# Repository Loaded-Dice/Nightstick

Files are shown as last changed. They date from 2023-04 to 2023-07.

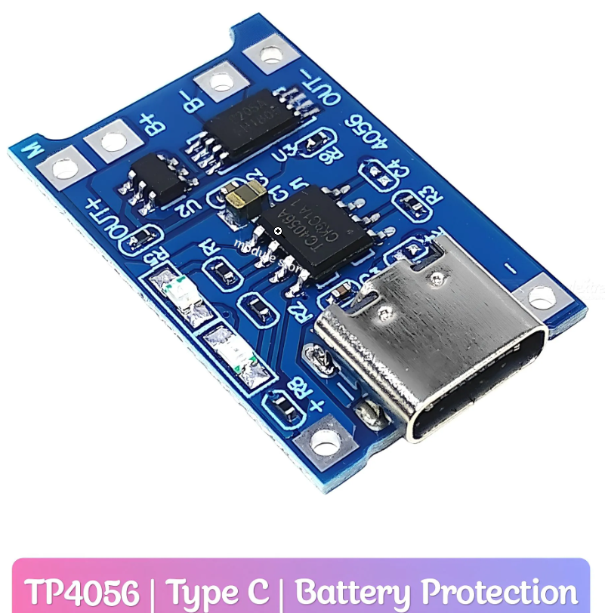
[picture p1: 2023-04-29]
Nightstick - DIY tutorial and Infos/LiPo Battery Charger Image.png

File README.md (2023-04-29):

# Nightstick
 
 Artistic LED toy - POV display style animated LEDs Arduino based code and DIY tutorial
 
 The main idea is to track the movement of the stick with an IMU (inertial measurement unit) 
 and display static images while the Nightstick is rotating
 
 This is not my first project, but the first one I publish on GitHub.
 
 Any tips, contributions or improvements are welcome.
 
 I'm still figuring things out :) 
 
 Readme Nightstick Main image

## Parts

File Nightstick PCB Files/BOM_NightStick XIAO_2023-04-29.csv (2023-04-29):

ID | Name | Designator | Footprint | Quantity | Manufacturer Part | Manufacturer | Supplier | Supplier Part | Price | link
1 | 100nF | C2,C5 | C0603 | 2
2 | 0.1u | C3 | C0603 | 1
3 | 1u | C4 | CAP-D5.0×F2.0 | 1
4 | TF-015 | CARD2 | TF-SMD_TF-015 | 1 | TF-015 | SOFNG | LCSC | C113206 | 0.031
5 | BSS138 | Q3 | BSS138 | 1 | BSS138 | ON Semiconductor | RS-Online | 671-0324 |  | https://www.onsemi.com/products/discretes-drivers/mosfets/bss138
6 | 10k | R1,R2,R3,R4,R5,R6 | R0603 | 6
7 | XIAO_NRF52840_SMD+Bat.TH | U1 | XIAO-NRF52840-SMD+BAT.TH | 1
8 | HW-373 6 Pin Batt Charger & BLM | U2 | HW-373 6 PIN BATT CHARGE & BLM | 1 | HW-373 | Shenzhen Hairuixing Technology Co., Ltd. |  | HW-373 |  | https://arduino.en.alibaba.com/product/62560363653-813084145/HW_373_1A_lithium_battery_charging_board_module_new_TYPE_C_USB_interface_charging_protection_two_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
9 | Switch | U3 | 2PIN CON | 1
10 | Btn ResArr | U4 | 3X SMD PAD 2X2MM | 1
11 | Main Conn | U5 | 4 PIN CONN | 1

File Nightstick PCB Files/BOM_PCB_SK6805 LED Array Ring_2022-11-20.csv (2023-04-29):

ID | Name | Designator | Footprint | Quantity | Manufacturer Part | Manufacturer | Supplier | Supplier Part | Price
1 | 2x2 Pin Header Square | U3 | 2X2 PIN CONN SQUARE | 1
2 | 100nF | C1,C2,C3,C4,C5,C6,C7,C8,C9,C10,C11,C12 | C0603 | 12 | CC0603KRX7R9BB104 | YAGEO | LCSC | C14663 | 0.002
3 | SK6805-EC15 | LED1,LED2,LED3,LED4,LED5,LED6,LED7,LED8,LED9,LED10,LED11,LED12 | LED-SMD_4P-L1.5-W1.5-BL | 12 | SK6805-EC15 | 欧思科光电 | LCSC | C2890035 | 0.172

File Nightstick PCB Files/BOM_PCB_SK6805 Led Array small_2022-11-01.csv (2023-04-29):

ID | Name | Designator | Footprint | Quantity | Manufacturer Part | Manufacturer | Supplier | Supplier Part | Price | Pins
1 | 100nF | C1,C2,C3,C4,C5,C6,C7,C8,C9,C10,C11,C12 | C0603 | 12 | CC0603KRX7R9BB104 | YAGEO | LCSC | C14663 | 0.002 | 2
2 | SK6805-EC15 | LED1,LED2,LED3,LED4,LED5,LED6,LED7,LED8,LED9,LED10,LED11,LED12 | LED-SMD_4P-L1.5-W1.5-BL | 12 | SK6805-EC15 | 欧思科光电 | LCSC | C2890035 | 0.172 | 4
3 | 3Pin In | U1 | 3PIN CON | 1 |  |  |  |  |  | 3
4 | 3 Pin Out | U2 | 3PIN CON | 1 |  |  |  |  |  | 3

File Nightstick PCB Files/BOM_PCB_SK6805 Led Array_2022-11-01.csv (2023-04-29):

ID | Name | Designator | Footprint | Quantity | Manufacturer Part | Manufacturer | Supplier | Supplier Part | Price | Pins
1 | Dat2 A | U3 | PAD 0.8 X 6 | 1 |  |  |  |  |  | 1
2 | Dat3 A | U4 | PAD 0.8 X 6 | 1 |  |  |  |  |  | 1
3 | Dat2 B | U8 | PAD 0.8 X 6 | 1 |  |  |  |  |  | 1
4 | Dat3 B | U9 | PAD 0.8 X 6 | 1 |  |  |  |  |  | 1
5 | Jumper - Bridge - SMD | U2 | JUMPER - BRIDGE - SMD | 1 |  |  |  |  |  | 2
6 | D_In | U1 | 1PIN TH ROUND | 1 |  |  |  |  |  | 1
7 | D_Out | U5 | 1PIN TH ROUND | 1 |  |  |  |  |  | 1
8 | VBat | U7,U18 | 1PIN TH ROUND | 2 |  |  |  |  |  | 1
9 | Vcc B | U14 | 1PIN TH ROUND | 1 |  |  |  |  |  | 1
10 | Vcc A | U16 | 1PIN TH ROUND | 1 |  |  |  |  |  | 1
11 | SK6805-EC15 | LED1,LED2,LED3,LED4,LED5,LED6,LED7,LED8,LED9,LED10,LED11,LED12,LED13,LED14,LED15,LED16,LED17,LED18,LED19,LED20,LED21,LED22,LED23,LED24,LED25,LED26,LED27,LED28,LED29,LED30,LED31,LED32,LED33,LED34,LED35,LED36,LED37,LED38,LED39,LED40,LED41,LED42,LED43,LED44,LED45,LED46,LED47,LED48,LED49,LED50,LED51,LED52,LED53,LED54,LED55,LED56,LED57,LED58,LED59,LED60,LED61,LED62,LED63,LED64,LED65,LED66,LED67,LED68,LED69,LED70,LED71,LED72,LED73,LED74,LED75,LED76,LED77,LED78,LED79,LED80,LED81,LED82,LED83,LED84,LED85,LED86,LED87,LED88,LED89,LED90,LED91,LED92,LED93,LED94,LED95,LED96,LED97,LED98,LED99,LED100,LED101,LED102,LED103,LED104,LED105,LED106,LED107,LED108,LED109,LED110 | LED-SMD_4P-L1.5-W1.5-BL | 110 | SK6805-EC15 | 欧思科光电 | LCSC | C2890035 | 0.172 | 4
12 | Gnd A | U10 | 1PIN TH SQUARE | 1 |  |  |  |  |  | 1
13 | Gnd B | U12 | 1PIN TH SQUARE | 1 |  |  |  |  |  | 1
14 | 100nF | C1,C2,C3,C4,C5,C6,C7,C8,C9,C10,C11,C12,C13,C14,C15,C16,C17,C18,C19,C20,C21,C22,C23,C24,C25,C26,C27,C28,C29,C30,C31,C32,C33,C34,C35,C36,C37,C38,C39,C40,C41,C42,C43,C44,C45,C46,C47,C48,C49,C50,C51,C52,C53,C54,C55,C56,C57,C58,C59,C60,C61,C62,C63,C64,C65,C66,C67,C68,C69,C70,C71,C72,C73,C74,C75,C76,C77,C78,C79,C80,C81,C82,C83,C84,C85,C86,C87,C88,C89,C90,C91,C92,C93,C94,C95,C96,C97,C98,C99,C100,C101,C102,C103,C104,C105,C106,C107,C108,C109,C110,C111 | C0603 | 111 | CC0603KRX7R9BB104 | YAGEO | LCSC | C14663 | 0.002 | 2

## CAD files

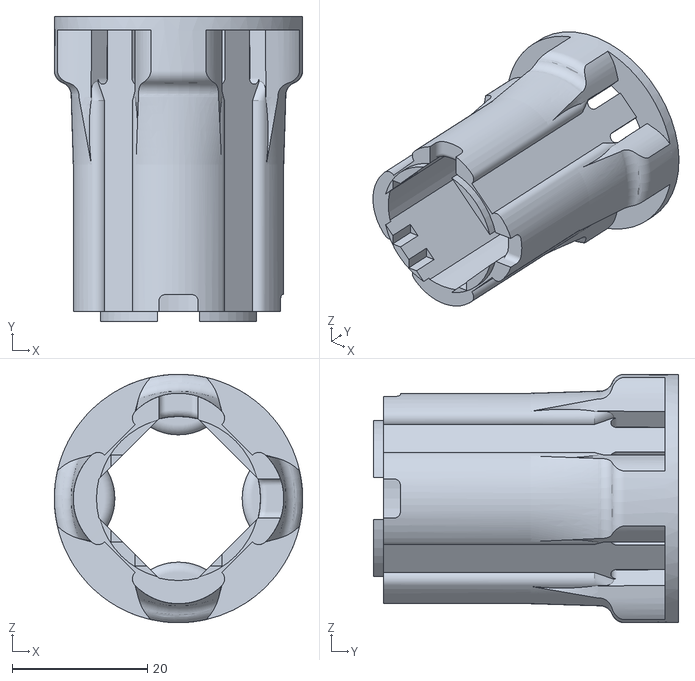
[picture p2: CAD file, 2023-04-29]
Nightstick 3D Print Files/Core Side B.stl
36.8 x 45.2 x 36.8

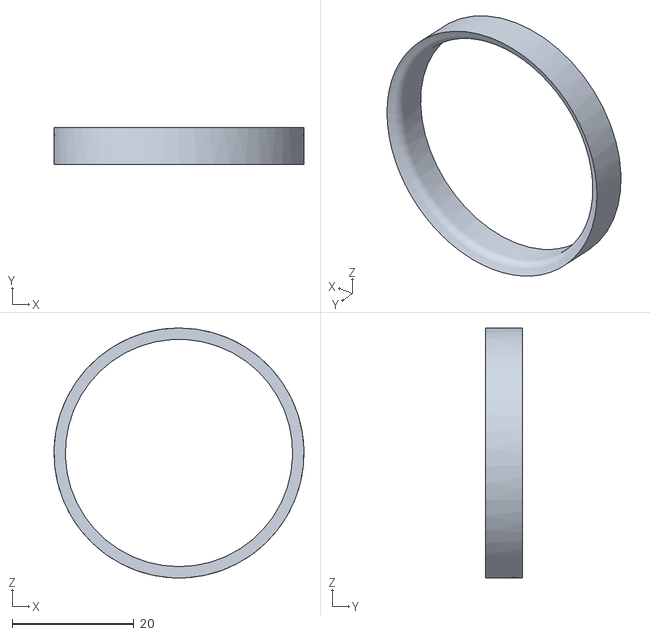
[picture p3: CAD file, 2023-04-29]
Nightstick 3D Print Files/2x Inner Ring.stl
41.1 x 6.05 x 41.1

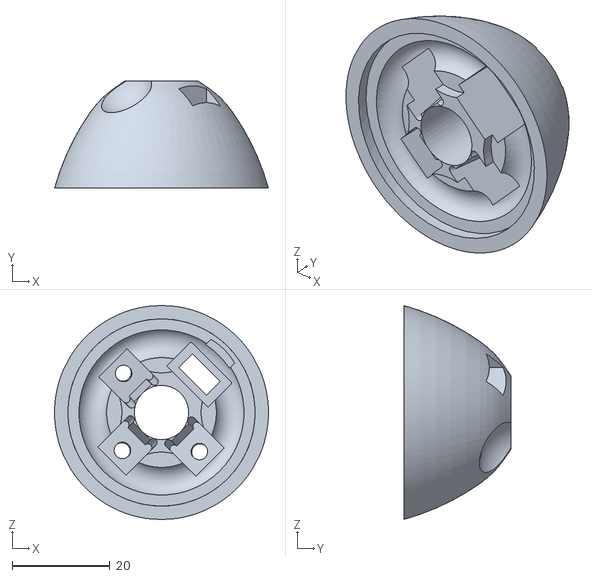
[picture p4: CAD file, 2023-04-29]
Nightstick 3D Print Files/Socket Side A.stl
43.8 x 22.0 x 43.8

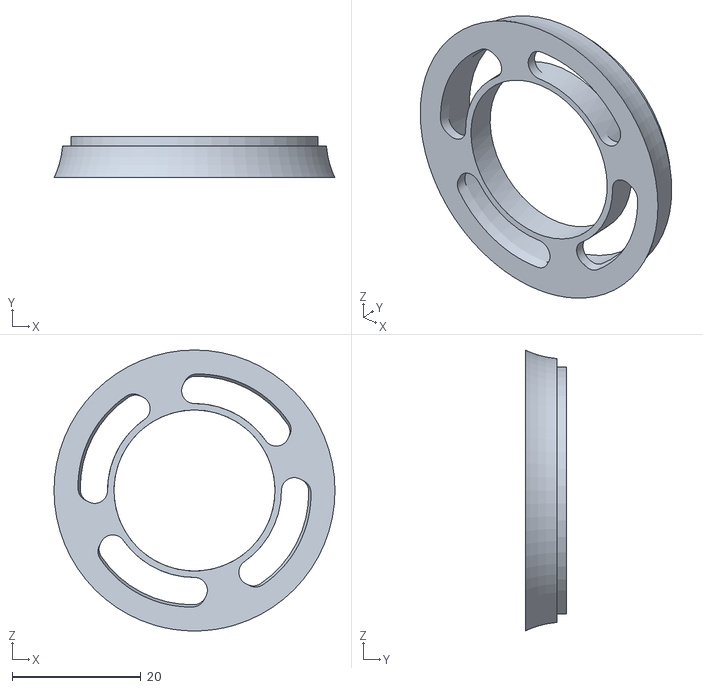
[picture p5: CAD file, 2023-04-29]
Nightstick 3D Print Files/2x Flower Anchor.stl
43.6 x 6.43 x 43.6

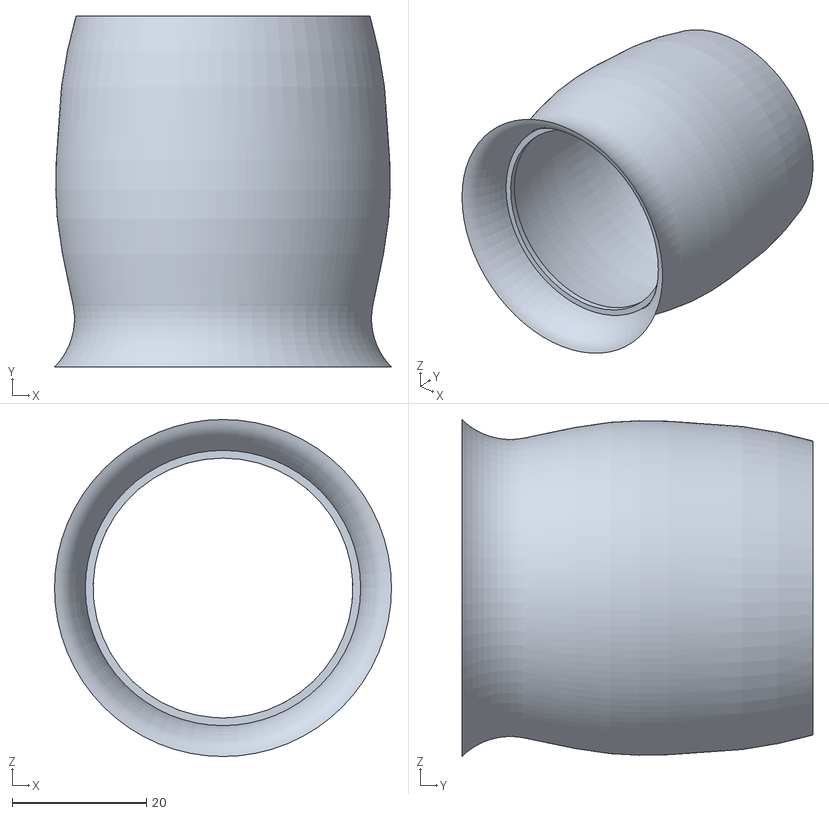
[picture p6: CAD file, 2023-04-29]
Nightstick 3D Print Files/2x Flex Cover.stl
50.2 x 52.3 x 50.2

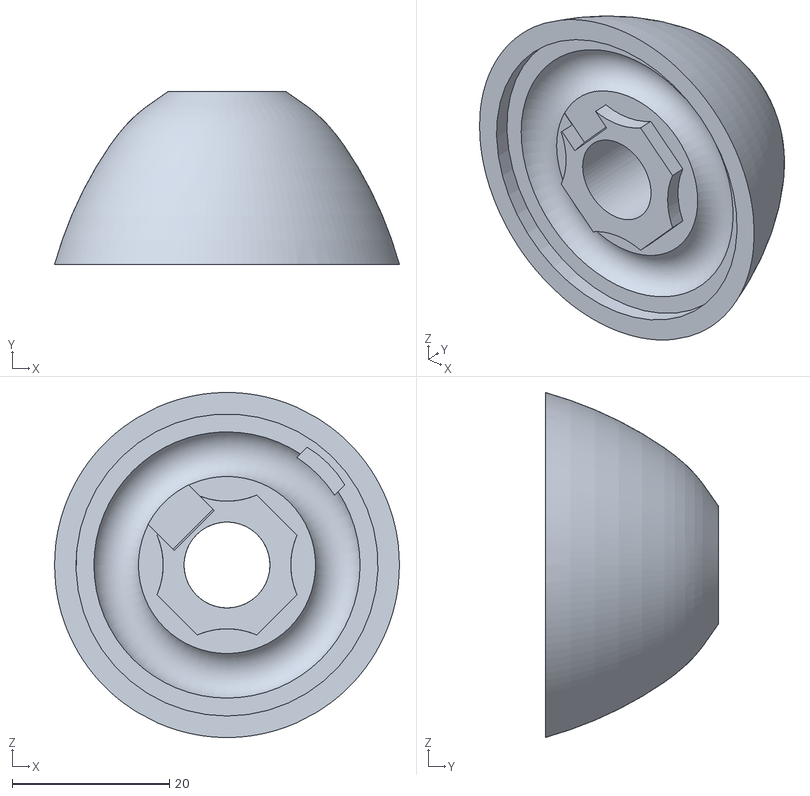
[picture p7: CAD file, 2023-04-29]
Nightstick 3D Print Files/Socket Side B.stl
43.8 x 22.0 x 43.8

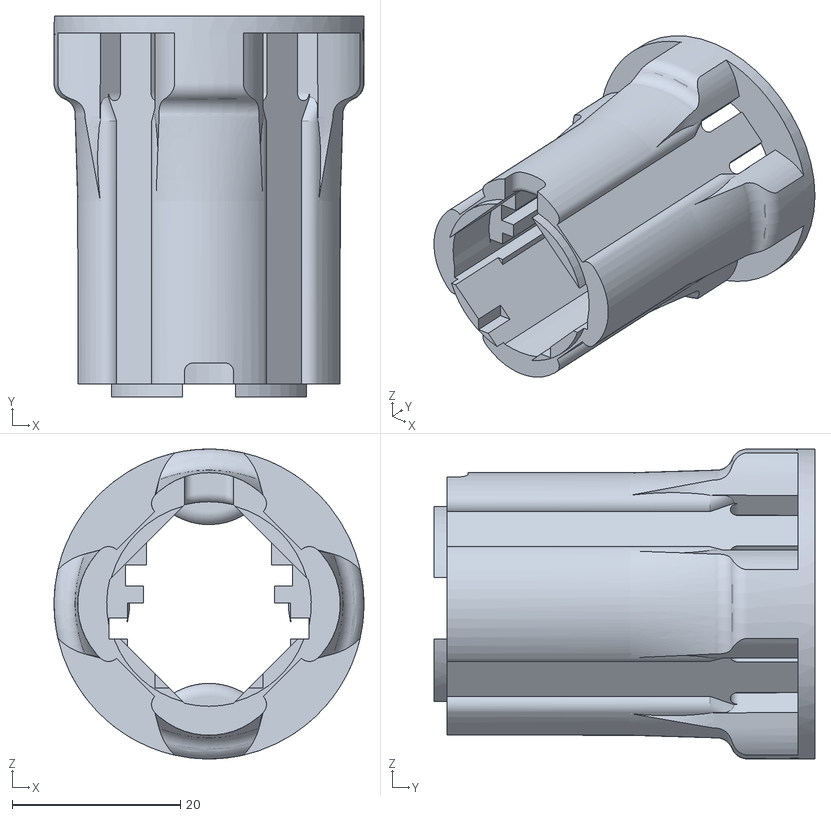
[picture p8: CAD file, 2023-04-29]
Nightstick 3D Print Files/Core Side A .stl
36.8 x 45.2 x 36.8

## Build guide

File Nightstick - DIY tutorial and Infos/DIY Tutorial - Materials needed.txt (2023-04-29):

 
Materials & parts needed to build the Nightstick:

  Acrylic Tube clear, length 50cm, 10/6 mm (outer/inner diameter)
  Silicone tube, length 50cm, inner diameter 10mm, thickness 1mm
  Transparent glue with white pigments / translucent white glue to fill the inner part of the acrylic tube after PCB insertion
  Pay attention to what glue or resin you use. 
	Most 2 component resins are very aggressive and begin dissolving the acrylic tube when put in the tube.
  	The resin should also not expand or contract when curing, 
  	should be UV resistant,
  	should not become yellow over time, 
  	should not react too exothermic when curing
  	Should be flexible enough to not break when the stick bends
  	But also robust and hard enough to support the structural integrity of the acrylic tube
	use a viscous glue to avoid air bubbles inside the stick

  I used UV special curing resin which worked good
  TPU-Sheet clear/transparent thickness >= 0.2mm  for the flowers
   (or Elastic clear/transparent rubber or silicone band)

  PCBs to order for one Nightstick:
    1x Main PCB for XIAO nRF52 & SD card 
    	- not assembled by PCB manufacturer 
	- further electronic parts needed, See list below 
	- PCB files are not panelized
    8x Short LED strip (one panelized) PCB 
    	- assembled by PCB manufacturer 
	- PCB files are panelized - 8 short LED strips on one PCB
    2x Main LED Strip (one panelized) PCB 
    	- assembled by PCB manufacturer 
    	- PCB files are panelized - 2 Main LED strips on one PCB)
    4x Led Ring PCB 
    	- assembled by PCB manufacturer 
	- PCB files are not panelized - one PCB = one LED ring
  
  Parts needed for factory side assembly: 
    Theoretically:
    364 pcs. SK6805-EC15 (footprint 1515 ) RGB LEDs  (see Led Datasheet)
    and almost same amount of 100nF capacitors (see BOM file in PCB folder)

   But in reality, the minimum order amount of a PCB is 5 pcs (at JLCPCB)
   also when using JLCPBC you need to buy the LEDs before ordering the PCBs 

  Further electronic parts for one Nightstick:
    1x Seeed Studio XIAO nRF52840 BLE Sense
    1x Micro SD card
    1x Micro SD Card Socket (See PDF datasheet)
    1x Lithium Battery Charging Board with Battery Protection Dual Functions 5V 1A Type-C TP4056 HW-373 V1.0 TP4056 (See image)
    1x LiPo Battery type 18350  (I used: Efest 18350 Gold, 900mAh, unprotected, flat anode) 
    2x 100nF Capacitor C0603
    1x 0.1µF Capacitor C0603
    1x 1µF electrolytic capacitor CAP-D5.0×F2.0
    1x 3-pin switch
    3x Push button (long cone)
    1x BSS138N or similar to raise LED data voltage level
    6x 10k SMD Resistor R0603
    Male & Female 2 Pin connector of your choice to connect the battery
    Some cables to wire everything up
    
  3D Files to print the housing
   1x  Socket Side A     	PLA Transparent/Clear
   1x  Socket Side B     	PLA Transparent/Clear
   1x  Core Side A       	PLA Transparent/Clear
   1x  Core Side B       	PLA Transparent/Clear
   2x  Flex Cover        	Recreus Filaflex 82A Clear (or similar flexible filament : Shore 82A)
   2x  Flower Anchor	 	PLA Transparent/Clear
   2x  Inner Ring        	PLA Transparent/Clear
  Missing:
   1x  Cover Plate Side A 	PLA Transparent/Clear
   1x  Cover Plate Side B 	PLA Transparent/Clear

  Other stuff needed
    copy SD Card Files (copy Nightstick folder and subfolders to your micro SD)

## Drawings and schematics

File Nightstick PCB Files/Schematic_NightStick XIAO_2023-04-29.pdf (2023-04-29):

A | A

1

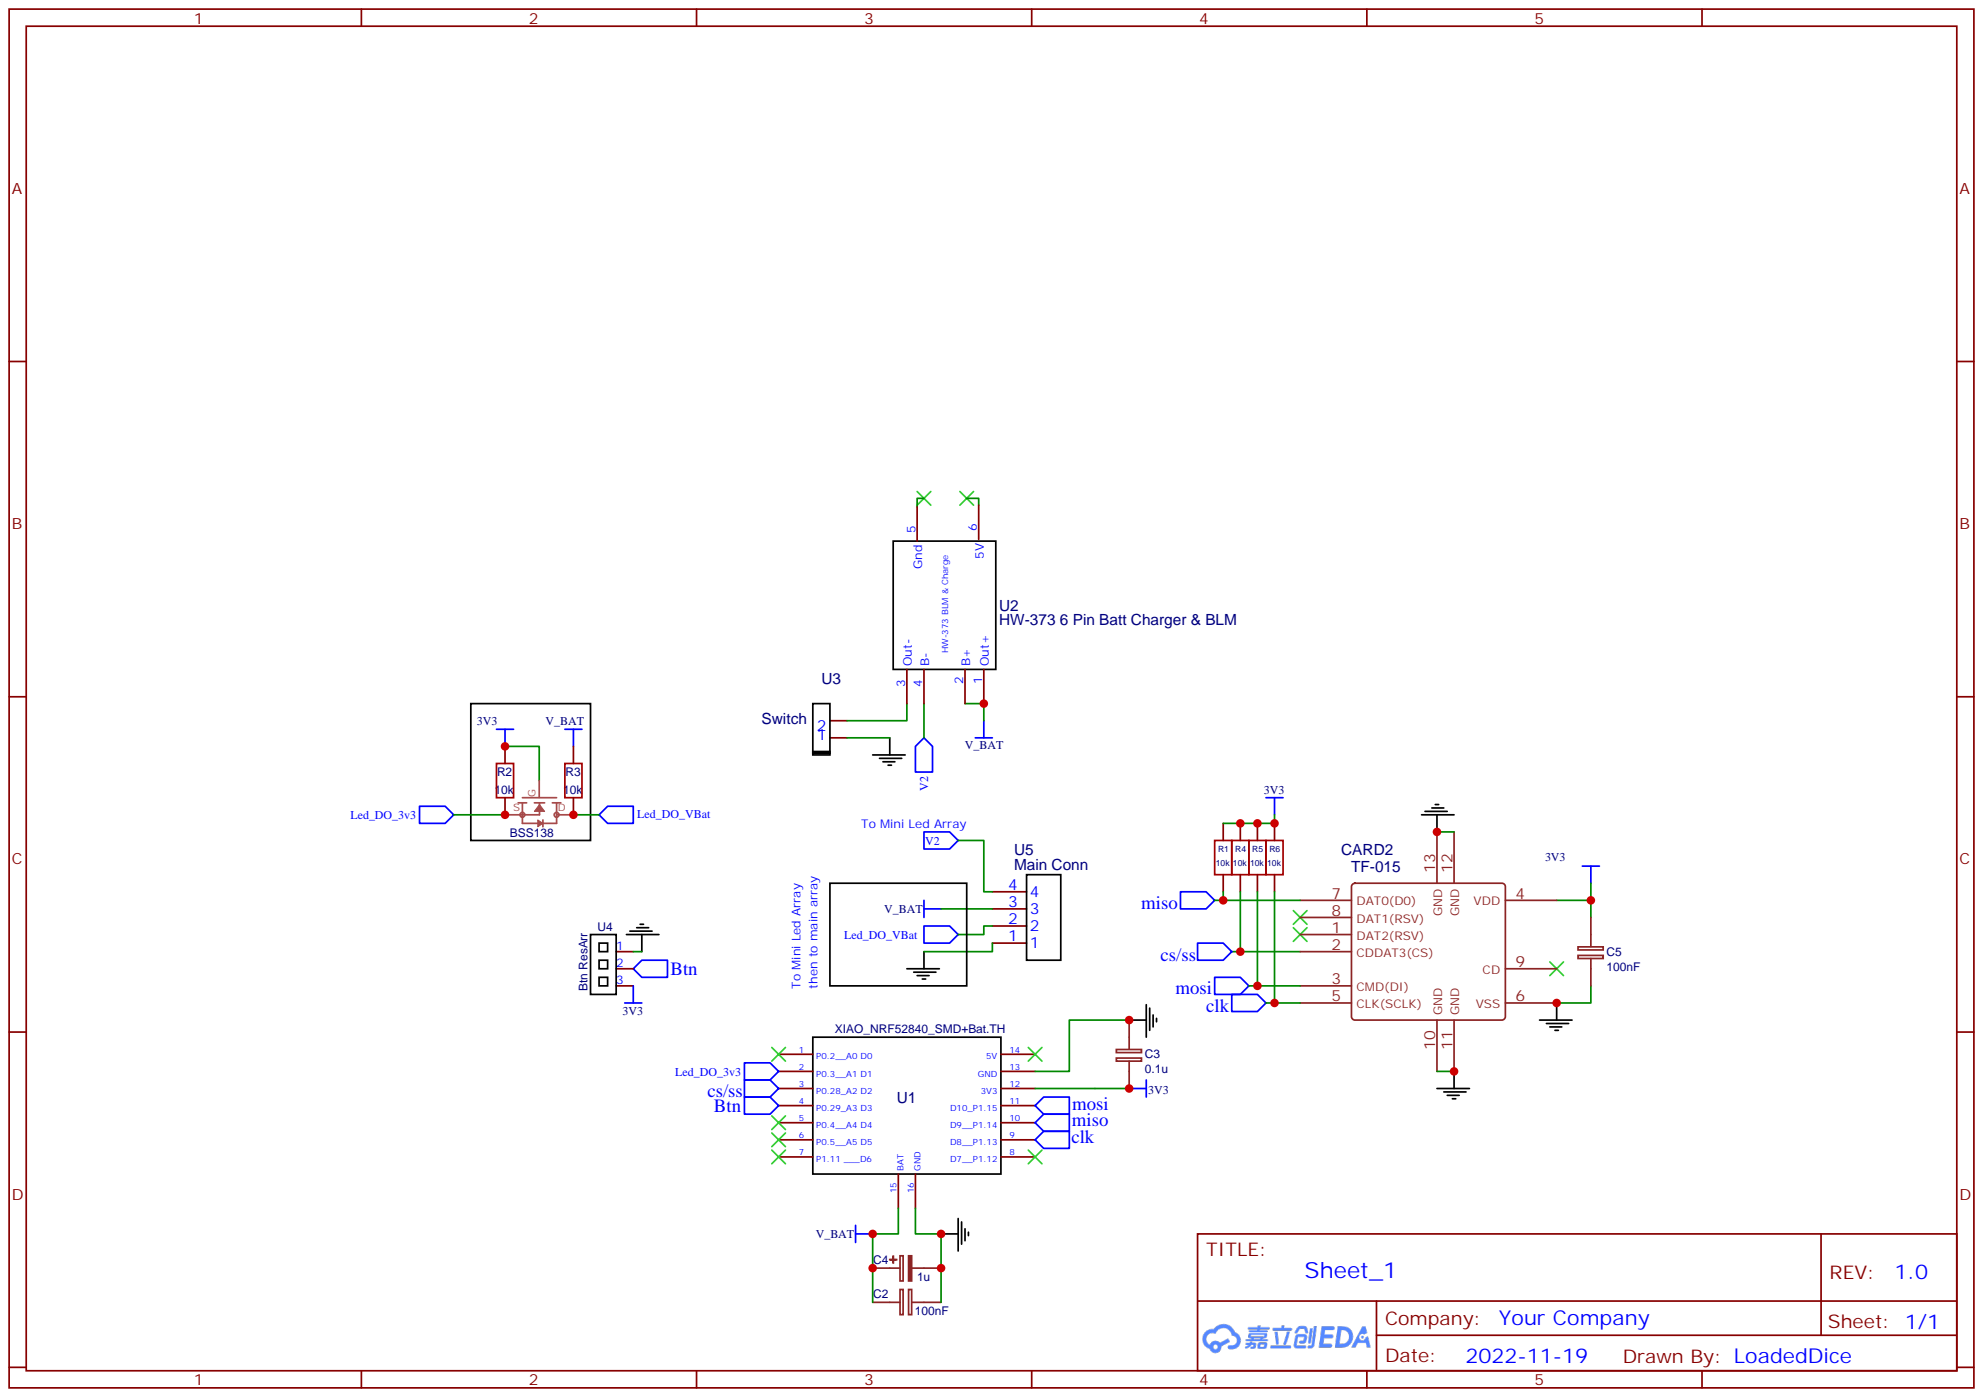
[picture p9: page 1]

HW-373 6 Pin Batt Charger & BLM

To Mini Led Array

then to main array

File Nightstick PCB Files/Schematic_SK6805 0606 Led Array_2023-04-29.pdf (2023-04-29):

## Pad ¹

## Pad U3 1

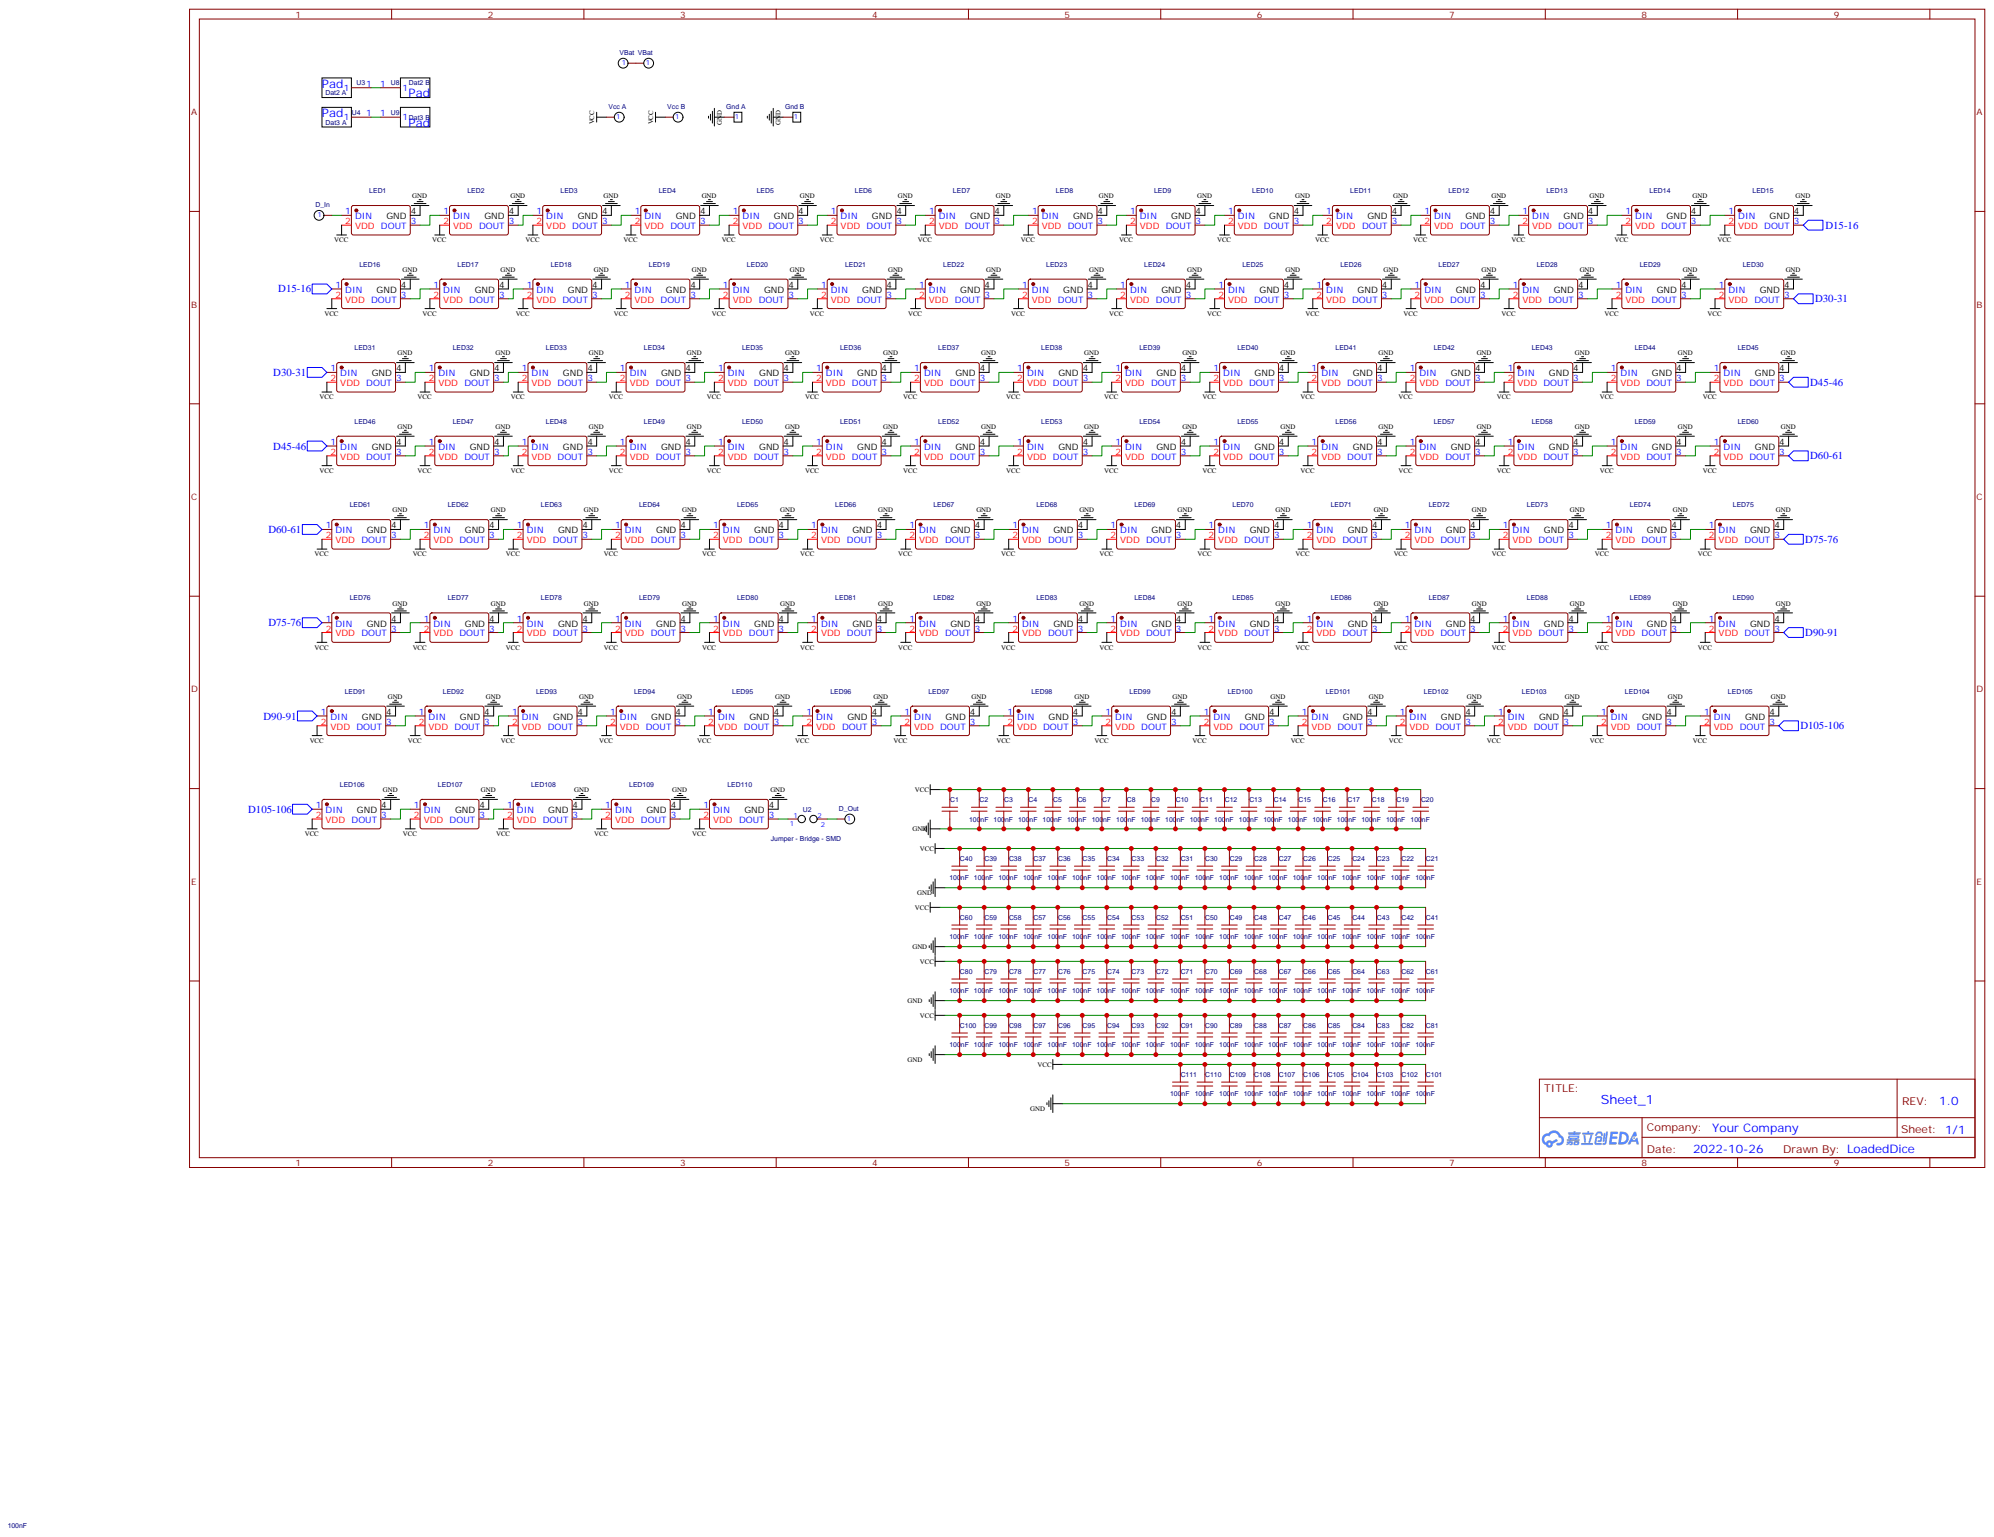
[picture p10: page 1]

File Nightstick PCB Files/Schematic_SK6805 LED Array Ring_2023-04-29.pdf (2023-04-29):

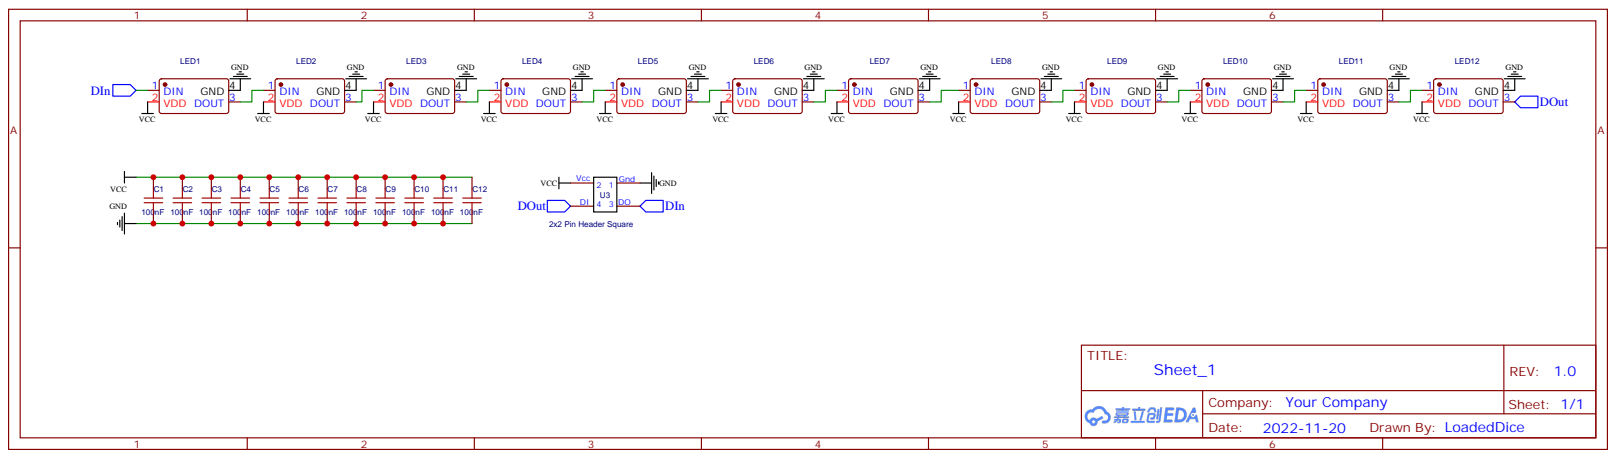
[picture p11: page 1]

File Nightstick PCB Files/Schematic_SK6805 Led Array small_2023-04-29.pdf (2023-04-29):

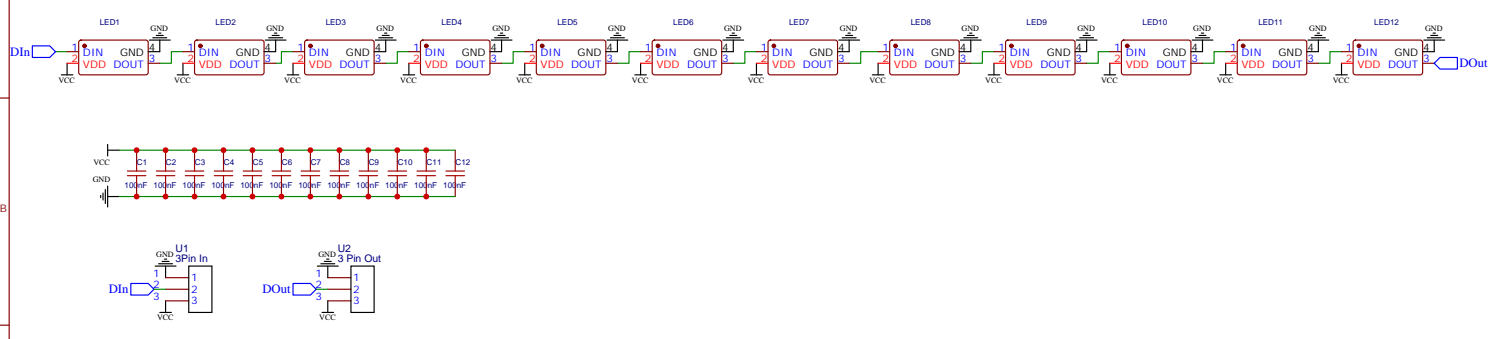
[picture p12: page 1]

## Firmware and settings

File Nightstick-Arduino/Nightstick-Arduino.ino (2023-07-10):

/*
               -------------------
 ------=======|  NIGHTSTICK CODE  |=======-------
               -------------------
           ---=={ Version 0.1.6 }==--- 
                by Marlon Graeber
                aka "Loaded Dice"
  You can find this code, DIY instuctions for the 
  Nightstick, PCB files and bitmap images to display on:
        https://github.com/Loaded-Dice/Nightstick         
        
  IDE used Arduino 1.8.19
  Board: Seeed Studio XIAO nRF52840 BLE Sense
  Core: Seeed Studio nRF52 Boards v1.1.1 (Not the mbed -enabled core!)
        https://files.seeedstudio.com/arduino/package_seeeduino_boards_index.json

  Board specs:
  Procesor: Nordic nRF52840 - ARM® Cortex®-M4 with FPU run up to 64 MHz
  Wireless:     Bluetooth 5.0/NFC/Zigbee
  Flash:  1 MB flash and 256 kB RAM
  Ext. flash  2 MB QSPI flash
  Board RAM size 256 kB
  Interface / Pins     1xUART, 1xIIC, 1xSPI, 1xNFC, 1xSWD / (11xGPIO(PWM), 6xADC)
  Circuit operating voltage: 3.3V@200mA
  Charging current: 50mA/100mA (internal) / 1A external
  Input voltage (VIN): 5V
  Standby power consumption:  <5μA

  never set VBAT_ENABLE to high - keep it always low!
  Button voltage divider level is max 3v3 regulated (not battery voltage) 
  Lowest voltage before BLM Charging module cutts off = 2.6V
  
  Can't programm the XIAO nRf52?

  when XIAO nrf is stuck and can't be programmed - double tap reset btn while powered via USB-C
  xiao nrf should appear as flash storage in windows when sucessfull.

  Dependencies:
  - FastLed (Version3.5 ) only used for the color, math & timing functions 
    because hardware otuput is'nt possible with XIAO nRF52 and FastLED.
    (The nRF52 architecture is not fully supported)
        https://github.com/FastLED/FastLED/
        
  - Adafruit NeoPixel (Version 1.11.0) needed for Hardware LED data output (just a workaround)
        https://github.com/adafruit/Adafruit_NeoPixel
        
  - Bluefruit (Version 0.21.0 ) Adafruit Bluefruit nRF52 Libraries - Bluetooth Low Energy library
      already included in XIAO nRF52 core librarys  ( https://github.com/adafruit/Adafruit_nRF52_Arduino )
      
  - SdFat - Adafruit Fork (Version 2.2.1)
        https://github.com/adafruit/SdFat
        
  - Arduino_LSM6DS3 (Inertial measurement unit library Arduino_LSM6DS3 v1.0.2)
        https://www.arduino.cc/reference/en/libraries/arduino_lsm6ds3/

  - SensorFusion (Version 1.0.6) - Mahony and Madgwick algorithms.
        https://github.com/aster94/SensorFusion
    
  - arduinoFFT (Version 1.6)
    https://github.com/kosme/arduinoFFT

  - PDM (Pulse Density Modulation)
    Part of the core library Seeed Studio nRF52 Boards v1.1.1 (Not the mbed -enabled core!)
    https://files.seeedstudio.com/arduino/package_seeeduino_boards_index.json
      
## Credits

This code is written by Marlon Graeber aka "Loaded Dice" 

## License

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
To do:

  New Featues to implement:
    
    - Use EQ  overlay animations
    - make compatible android app and / or lilygo smartwatch code to communicate via BLE with the stick, change settings, lookup battery status....
  
  Improvements & next steps:

    - check if the flat led byte array is loaded correctly (by width & height meta info)
    - create an MAIN_PATH/System/error_log.txt file with  millis() timestamp and error message
    - also on bootup search for the error_log.txt and print to serial via msg() and msgln()
    - config struct should control controls main stick states (switch variables like  BRIGHTNESS to cfg.bright and so on)
    - Store contents of the Readme.txt file in progmem and write it to sd card if the file is not present or file size is different
    - when SD card is empty create folder structre and Files: MAIN_PATH, MAIN_PATH/BMPs, MAIN_PATH/System, MAIN_PATH/readme.txt, MAIN_PATH/config.csv (config done!) ...
    - in Led2Pixel_static() uint16_t ledPixelPos[NUM_LEDS][n]; where n=0 --> bmp x pos n=1 --> bmp y pos for each led
      currently ledPixelPos is rounded to thethe next whole pixel - instead of rounding directly multiply x&y floats by 10 an then rounding the value
      use the extra precision to implement a blending function to blend with the surrounding pixels (smoother transition)
    - Don't output data to stick like a simple line of LEDs. Introduce a virtual_NUM_LEDS (use the 4 led strips in the flower head as one)--> Look at LEDs mirrorStick()  
    - implemet deep sleep for µC or idle animation when not played (make this selectable in config )
    - indicate button push by single leds in the 1st ring light up
    - create ring LED & mini strip roll angle offset detection sequence by lighting up first ring LED of each ring and first LED of each mini LED strip
      one by one  and for each lit up LED the sick need to ged rotatet so that the LED is pointing up( right above the center line)
      one button press sould store the roll angle value and ne next led should light up. Calibration values sould get stored in the config file
      and loaded when the stick boots
    - More palettes, preview / palette knife?
    - Animation idea - charge juggle animation within  the flowers before shooting  to the other side and stay a moment inside the other side to charge up
      maybe simulaniously shoot and intersect in the middle 
    - cylon faster & brighter
    - edit animation path in the outer flowers for all animations 
    - exclude fire & water palettes on palette cycle 

  next version main PCB:
  
    - castellated holes for battery contact? contact surface pads?
    - add (electrolytic) capacitor to main pcb (SMD 10uF)
    - make a mini push button pcb: curved, buttons pointing down, sesistor array on the opposite side oth the btns
    - Test BAT60A-E6327 Schottky Diode 10V 3A  SOD323 with Bat+ contact to power main processor
    - high side switch / load switch to switch led array power?  and/or processor power (self retaining push btn power on?)
    - put a connector terminal on the bottom - like ZH 1.5 mm (4 & 6 pin; pins) (90 degree angled connector)

  3D case design improvements
    - improved battery holder
    - btn pcb opening
    - less infill for socket and inner core
    - manual weight distribution

        Pinout:
                                   ______
--------|-----|------|----     ___| USBC |___    -----|-------|------
        |     | (A0) | D0     |O  |______|  O|     5V |
  LEDs  |     | (A1) | D1     |O|----------|O|     GND|
  SDCS  |     | (A2) | D2     |O|   XIAO   |O|     3V3| ! Not constant ! but scaling proportional with battery voltage
  Btn   |     | (A3) | D3     |O| nRF52840 |O|     D10| (A10) | MOSI
        | SDA | (A4) | D4     |O|   BLE    |O|     D9 | (A9)  | MISO
        | SCL | (A5) | D5     |O|  SENSE   |O|     D8 | (A8)  | SCK
        | Tx  | (A6) | D6     |O|__________|O|     D7 | (A7)  | Rx
                               --------------


      |------|------|------|--------------|   Planned for
      | ⁪Pin  | GPIO | Pin  | Function     |   next PCB Version
      |------|------|------|--------------|--------------------------
      | D0   |  2   ⁪| A0   |              |   nRF EN 
      | D1   ⁪|  3   ⁪| A1   | LEDs DO      |
      | D2   ⁪|  4   ⁪| A2   | SD CS        |
      | D3   ⁪|  5   ⁪| A3   | Buttons A In |
      | D4   ⁪|  6   ⁪| SDA  |              |   VccLed EN
      | D5   ⁪|  7   ⁪| SCL  |              |
      | D6   ⁪| 21   ⁪| Tx   |              |
      | --   ⁪| --   ⁪| ---- | ------------ |
      | D10  ⁪| 10   ⁪| MOSI | SD Card      |
      | D9   ⁪|  9   ⁪| MISO | SD Card      |
      | D8   ⁪|  8   ⁪| SCK  | SD Card      |
      | D7   ⁪| 20   ⁪| Rx   |              |
      |------|------|------|--------------|


    mode      | static   | trail    | Ani   | Fire | Ambient | brightness | battery  |
   -----------|----------|----------|-------|------|---------|------------|----------|
    A_SHORT   | next bmp | next bmp | Ani++ |      |         | bright++   |          |
    B_SHORT   | mode++        <-        <-     <-      <-         <-          <-     |
    C_SHORT   | last bmp | last bmp | Ani-- |      |         | bright--   |          |
    A_LONG    | next fld | next fld |       |      |         | Light on   |          |
    B_LONG    | mode--        <-        <-     <-      <-         <-          <-     |
    C_LONG    | last fld | last fld |       |      |         |Light off   |          |
    B_ULONG   | BLE I/O       <-        <-     <-      <-         <-          <-     |           
    BTN_AB    | palette++     <-        <-     <-      <-         <-          <-     |         
    BTN_CB    | palette--     <-        <-     <-      <-         <-          <-     |     
   -----------|----------|----------|-------|------|---------|------------|----------|      

    BTN_BA     // combo unused: to avoid bluetooth toggle by accident          
    BTN_BC     // combo unused: to avoid bluetooth toggle by accident   

   Main thoughts on the code structure:
   
     includes, definitions, Global variables & structs  are in the header file "Nightstick.h"
     Written in that order for each tab page section separated
     each tab gets its own setup function on the beginning of the page named setup_tabName() 
     and if routines need to run within the loop  i created a main_tabName() function right below the setup_tabName() function
     when a specific timing is needed for the main_ functions, a template function from the fastLED library is used (EVERY_N_MILLIS(n){})
     with the delay time defined in Nightstick.h
*/

#include "Nightstick.h"

//--------------------------------------------------------------------------------------------------------------------- Setup


void setup(){ 
  //do not use Serial.print() or Serial.println() instead use msg() or msgln() to implement a debug on/off message mode later
  Serial.begin(115200);
 // if(DEBUG){while (!Serial.available()) { if(Serial){EVERY_N_MILLIS(1000){Serial.println("Press any  key");}}yield();}}
//  Serial.print("TEST");
  setup_System(); // begin with system setup to enable error blink codes with the internal board leds
  setup_SD();     // boot sequence stops when SD card is removed (safety reason)
  setup_Config(); // find and load config.csv from SD card or write new if not found
  setup_Inputs();
  setup_Batt();
  start_FILTER_IMU();
  setup_BLE_COM();
  setup_LEDs();

  cfg.ledMode = LED_OFF;
  //startBLE(); // TEST
  

  //start_FFT();//
 // strip.setBrightness(25);
  //removeBmp("/Nightstick/BMPs/trails/elements/electric_tangle_wave.bmp");
    
//   ledMode = LED_TRAIL ; // LED_OFF;// LED_TEST; //
//   BMPtoRAM("/Nightstick/BMPs/trails/elements/purple_root.bmp");
//   strcpy(cfg.trailsBmp,"purple_root.bmp");
//   strcpy(cfg.trailsFolder,"elements");
}
// not good enough : colorWaves

// function pointer, name, active state
static const animations aniList[] = {
  {plasma,    "plasma",   true},
  {waveRings, "waveRings",true},
  {rainbow,   "rainbow",  true},
  {cylon,     "cylon",    true},
  {bpm,       "bpm",      true},
  {juggle,    "juggle",   true}
};
const uint8_t numAnis = SIZE(aniList); //(sizeof(aniList) / sizeof((aniList)[0]));



void loop(){ // all main functions have timining structures integrated
  timeStart(); 
  main_FILTER_IMU();
  main_LEDs();
  timeStop();
  main_BLE_COM(); 
  main_Batt();
  main_Inputs();
  
  //debugPrint(1000);
  //FFT_main(); 
//if(paletteNextAuto){Serial.print(millis()); Serial.print("\t paletteNextAuto on - ani: ");Serial.print( currentAni);Serial.println(aniList[currentAni].aniName);}
//if(paletteFadeAuto){Serial.print(millis()); Serial.print("\t paletteFadeAuto on");Serial.print( currentAni);Serial.println(aniList[currentAni].aniName);}
//if(paletteFadeAuto && paletteNextAuto){Serial.print("both on - long delay"); Serial.println(); delay(10000);}

}




unsigned long  tempTimer = 0;
float timeResult = 0.0;

void timeStart(){
  tempTimer = micros();
 
}
void timeStop(){
  tempTimer = micros() - tempTimer;
  timeResult = ((float)tempTimer / 1000.0);
}
void debugPrint(int delayMS){
  static unsigned long debugTimer;
  if(millis() > debugTimer + delayMS){
//  debugBuff[0]='\0'; // clear buffer
//  strcpy(debugBuff,f2char(yaw));
//  strcat(debugBuff,"\t");
//  strcat(debugBuff,f2char(pitch));
//  strcat(debugBuff,"\t");
//  strcat(debugBuff,f2char(roll));
//  strcat(debugBuff,"\t");
  Serial.print(yaw);
  Serial.print('\t');
  Serial.print(pitch);
  Serial.print('\t');
  Serial.print(roll);
  Serial.print('\t');
  Serial.println(timeResult);
  debugTimer = millis();
  }
}

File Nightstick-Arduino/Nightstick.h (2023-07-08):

//--------------------------------------------------------------------------------------------------------------------- Common

//System Status indicator variables
//uint8_t bleMode = BLE_OFF; // BLE_OFF , BLE_ADV , BLE_CONN
//uint8_t ledMode = LED_OFF;// LED_TEST; //LED_TRAIL...
//uint8_t imuMode = OFF; // ON OFF
//uint8_t fftMode = OFF; // ON OFF
//---==={DEFINITIONS - COMMON / PINS}===---//
#define LED_PIN     D1
#define SDCS_PIN    D2
#define BTN_PIN     A3
//---==={DEFINITIONS - COMMON / DELAYS}===---//
//#define DELAYMS_FILTERIMU 10 // 100Hz or 10 ms fixed
#define DELAYMS_SHOWLED   25 // 100Hz
#define DELAYMS_FILTER    25 // 100Hz
#define DELAYMS_READBTN   30 //
#define DELAYMS_READBATT  300  //1000
#define DELAYMS_LEDOFF    2000  //
//--=={DEFINITIONS - COMMON / Inputs}==--//


#define BTN_A_VAL       2504
#define BTN_B_VAL       1775
#define BTN_C_VAL       787
#define BTN_AB_VAL      2839
#define BTN_BC_VAL      2034
#define BTN_RANGE   50    //value +/- Range
#define BTN_MIN     500  // if value > BTN_MIN --> btn-pressed else relese
#define LONGTIME    450 // time in ms
#define MAXTIME  900
#define A_SHORT   1
#define B_SHORT   2
#define C_SHORT   3
#define A_LONG    4
#define B_LONG    5
#define C_LONG    6
#define B_ULONG   7
#define BTN_AB    8
#define BTN_BA    9
#define BTN_CB    10
#define BTN_BC    11

// ---==={VARIABLES - Inputs}===---//
struct Btn{
    uint16_t aVal = 0;
    char firstBtn = ' ';
    uint16_t aValPressed = 0;
    unsigned long timer;
    unsigned long wait = 0;
    bool prepare =false;
    bool blocked = false;
};
Btn btn;

//---==={DEFINITIONS - COMMON / System}===---//
//#include <avr/dtostrf.h>
#define DEBUG false
#define SIZE(ARRAY)    (sizeof(ARRAY) / sizeof(ARRAY[0]))
#define ON  true
#define OFF false
#define NEXT  1 // changing folder and bmps
#define LAST -1 // changing folder and bmps
#define ERRLONG  1000 // for internal led blink timing
#define ERRSHORT 300  // for internal led blink timing
#define RAD(A)  (A * 71) / 4068.0  // convert degree to radians
#define DEG(A)  (A*4068) / 71.0    // convert radians to degree
#define RADTO16(A) (A * 10430.378350) // A / (2 * M_PI) * 65535
#define DEGTO16(A) (A * 182.044444) // A / 360 * 65535
#define U16TORAD(A) (A / 10430.378350) //
#define U16TOGED(A) (A / 182.044444) // A / 360 * 65535
#define OFF false
#define On true     

#define FREQ2MS(A) 1000/A
#define MS2FREQ(A) 1000/A
#define MAIN_PATH "/Nightstick"  // Main Folder on SD where BMPs Folder is in
#define SUBFLD_BMP "/BMPs"
#define SUBFLD_TRAIL "/trails"
#define SUBFLD_STATIC "/static"
#define CONFIGNAME "Config.csv"
#define FULLPATH_TRAILS (MAIN_PATH SUBFLD_BMP SUBFLD_TRAIL)
#define FULLPATH_STATIC (MAIN_PATH SUBFLD_BMP SUBFLD_STATIC)
//FULLPATH_TRAILS FULLPATH_STATIC
// MAIN_PATH SUBFLD_BMP
#define TYPE_FLD 0
#define TYPE_BMP 1
#define TYPE_CFG 2
#define MAXFILECHARS 51 // 50 + null
const char *  modeNames[] = {"Off","Static","Trail","Animation","Fire","Battery"};
// Dfinitions for ledMode ( determine only the current playing led animation)
#define LED_OFF       0
#define LED_STATIC    1
#define LED_TRAIL     2
#define LED_ANI       3
#define LED_FIRE      4
#define LED_BATT      5
#define LED_BLE       6
#define LED_TEST      7   // For testing new stuff

//---==={VARIABLES - COMMON / SYSTEM}===---//
uint8_t lastErrID = 0; // 
struct errInfo{  char msg[MAXFILECHARS]; bool logSD; char ch1; uint16_t t1; char ch2; uint16_t t2; bool ledLoop;};

static const errInfo errInfoArr[] PROGMEM = { // delay times defined ERRSHORT or ERRLONG
// |-----------------Error Message-------------------| log? |led1,delay1   ,led2 ,delay2   ,loop?      error ID (Array index)
  {"No Error"                                         ,false,'G' ,0        ,'G'  ,0        ,false},  //  0
  {"No SD Card detected"                              ,false,'R' ,ERRSHORT ,'R'  ,ERRSHORT ,true }   //  1
};

static const uint8_t errInfoCount = sizeof(errInfoArr)/sizeof(errInfo);


char charBuff[MAXFILECHARS*4];  // generic char buffer (BLE has own buffer)
char pathBuff[MAXFILECHARS*4];
char fileBuff[MAXFILECHARS];
char folderBuff[MAXFILECHARS];
//--------------------------------------------------------------------------------------------------------------------- Batt
//--=={DEFINITIONS - Batt}==--//
#define AVG_BATTREAD 4 // average batteryvoltage after n readings
//---==={VARIABLES - Batt}===---//
// vRefSet is 3.0V  bc.  the btn voltage div. analog in won't clip when using btns
float vRefSet = 3.0; //Internal selectable: 3.6 || 3.0 || 2.4 || 1.8 || 1.2
float vBat = 4.2;   // battery volatge (corrected)
uint8_t pBat = 100;   // battery percentage (3.65V to 4.2V);
float rawBat = 0.0;
float maxBat = 4.2;   // save scaled raw analog Batt val (for btn read volt.div.)
uint8_t initBatt = 0;
const uint16_t vLookUp[]   = {268,  278, 288, 298, 308, 318, 328, 339, 349, 359, 369, 379, 389, 399, 409, 419}; //( vBat*100 )
const uint16_t rawLookUp[] = {1168,1205,1239,1285,1315,1357,1398,1443,1488,1533,1566,1610,1650,1690,1733,1775}; //(Analog voltage @ 12 Bit; vRef = 3.0V)
//--------------------------------------------------------------------------------------------------------------------- SD
//---==={DEFINITIONS - SD}===---//
#include "SdFat.h"
#define SPI_CLOCK SPI_FULL_SPEED
#if HAS_SDIO_CLASS
#define SD_CONFIG SdioConfig(FIFO_SDIO)
#elif  ENABLE_DEDICATED_SPI
#define SD_CONFIG SdSpiConfig(SDCS_PIN, DEDICATED_SPI, SPI_CLOCK)
#else  
#define SD_CONFIG SdSpiConfig(SDCS_PIN, SHARED_SPI, SPI_CLOCK)
#endif  
//#define error(s) sd.errorHalt(&Serial, F(s))
#define FILECHARMAX 41 // 50 +  '\0' (null) 
//---==={VARIABLES - SD }===---//
SdFat32 sd;
File32 dir;
File32 file;

#define MAXPIXEL 40000 //--> 200x200px
#define BUFFPIXEL 512 // number of pixel to read in a row from SD
uint8_t pixelBuff[MAXPIXEL][3]; // --> 120kB

struct bmpInfo{
    File32 file;
    uint32_t fileSize;
    uint32_t headerSize;
    uint16_t width; // BMP image width in pixel
    int16_t height; // BMP image height in pixel
    uint8_t depth; // Bit depth (currently must report 24)
    uint32_t imageOffset; // Start of image data in file
    uint32_t rowSize; // Not always = bmpWidth; may have padding
    uint8_t sdbuffer[3 * BUFFPIXEL];
    uint32_t buffidx = sizeof(sdbuffer); // Current position in sdbuffer
    uint8_t povidx = 0;
    boolean goodBmp = false;
    boolean flip = true;
    int w, h;
    uint32_t pos = 0;
    int r, g, b;
};
bmpInfo bmp;
//--------------------------------------------------------------------------------------------------------------------- CONFIG
//---==={DEFINITIONS - CONFIG}===---//

#define TYPE_NONE   0
#define TYPE_BYTE   1
#define TYPE_INT    2
#define TYPE_FLOAT  3
#define TYPE_BOOL   4
#define TYPE_WORD   5
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

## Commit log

2023-04-29 Initial upload
    Initial upload of my first public project
    [2x Flex Cover.stl, 2x Flower Anker.stl, 2x Inner Ring.stl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]
2023-04-29 Included first version of a tutorial + infos
    This is just a first short version of a tutorial and assembly information. I will add a more detailed version of the tutorial when I build the next Nightstick
2023-04-29 file name changed
    [2x Flower Anchor.stl]
2023-05-05 several changes
    Battery voltage lookup table implemented
2023-05-10 fixed changing Vdd reference
    [BLE_COM.ino, Batt.ino, Inputs.ino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]
2023-05-12 Button input logic completed
2023-05-29 fixed display leds and rearrange led order
    [BLE_COM.ino, Config.ino, Filter_IMU.ino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]
2023-06-10 fixed bitmap trail display code
    [Config.ino, Filter_IMU.ino, Inputs.ino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]
2023-06-10 Switched from MahonyAHRS to MadgwickAHRS
2023-06-27 fixed: CRGB array overflow issue
    [LEDs.ino, LEDs_2.ino, Nightstick-Arduino.ino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]
2023-07-04 Changed filter library to SensorFusion + BLE com

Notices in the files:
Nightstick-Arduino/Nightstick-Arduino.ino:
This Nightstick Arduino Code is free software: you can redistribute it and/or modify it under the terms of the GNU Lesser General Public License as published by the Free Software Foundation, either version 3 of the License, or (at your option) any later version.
